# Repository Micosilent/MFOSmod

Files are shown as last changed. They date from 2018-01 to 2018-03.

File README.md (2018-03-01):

# MFOSmod

This is a collection of modules from Ray Wilson's [Music From Outer Space](http://musicfromouterspace.com/).

I will be using SMT in all the places I can, and replacing obsolete components that cant be found in the usual electronic distributors ( mouser or digikey ), with appropiate ones, following if possible Ray Wilson's advice on parts.

---

## MFOS SUPER-Modular Bundle

The idea is to end with all the modules from the supermodular bundle for starters, once we have all this modules we can look into transcripting other modules.

TODO:
- [x] 1. VCO
- [ ] 2. State Variable 12dB/Oct VCF
- [ ] 3. ADSR Envelope Generator
- [ ] 4. Mini-Controller
- [ ] 5. Dual Log/lin VCA
- [ ] 6. VC Low Frequency Oscillator
- [ ] 7. Dual AR Envelope Generator
- [ ] 8. Noise Cornucopia
- [ ] 9. Four Channel Stereo Panning Mixer
- [ ] 10. Delayed Modulation Module
- [ ] 11. Sample & Hold
- [ ] 12. Sonic Multiplier
- [ ] 13. Low Pass 24db/OCT VCF
- [ ] 14. Wave Freaker
- [ ] 15. Stereo Auto-Panner
- [ ] 16. Multi-Function Module
- [ ] 17. MFOS 8 Stage Phase Shifter
- [ ] 18. MFOS Voltage Quantizer

You dont really need all this modules to make a working synthesizer, but I am planning to make all the modules in KiCAD and start bulding them progresivly.

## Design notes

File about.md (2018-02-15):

# VCO

This is a compilation of logs and stuff that are later edited an posted on hackaday and blog.

## Log 1: Initial considerations

### Hardware
This synthesizer will be based on an eurorack form factor, as such the size for the front panel must comply with the "standard".

A typical synth enclosure is 6 HP units high, acomodating two rows of modules, each 3 high, and 84 HP units wide, so if we want a rack enclosure with 4 VCOs they should be 10 units wide, so they only take up half of the top row.

Following this guidelines, the aluminium front panel is 128.5mm high by 50.50mm width and the PCB in order to fit in normal fabhouse board size limits will be 100x50mm with a few mm of margin if we need the space.

The mounting of the pcb to the front pannel will be accomplished with the audio jacks and potentiometers, so no standoffs or mounting holes are needed.

The eurorack power connector, is a 8x2 with +-12V, +5V , GND and some control voltages, we could add a switch and do a small modification of the board, in order to accomodate for the control of the VCO with internal CV.

The frontpanel design will be transfered toner from a SVG design, and then coated with a few layers of lacquer.

The original design comes with a temperature compensator, wich after some research turns out to be synth lingo for a thermistor, a PTC thermistor to be more exact. The one used in the original design is a 2k with a very low tolerance. These have been proven difficult to find in the usual distributors, so two 1k .5% PTC thermistors in a 1206 and very close proximity to the matched transistor package will be used.

### Design

I am going to try to do a cool frontpanel design with inkscape, to help me with this I found a  bunch of plugin that im going to try. They can be downloaded 

1. Doepfer units: [here](http://syinsi.com/eurorack-panel-designer-for-inkscape/).

2. Knob scales: [here](https://github.com/leechwort/knob_scale_generator)

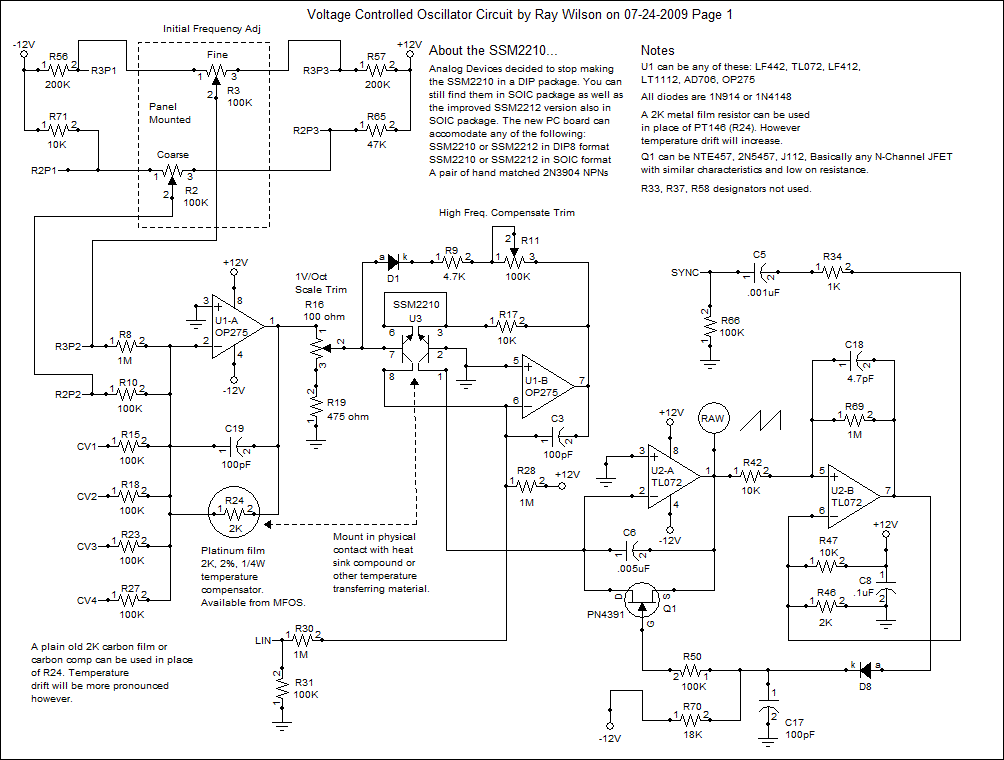
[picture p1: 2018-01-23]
VCO/media/vco20120615wsoic_page_1.gif

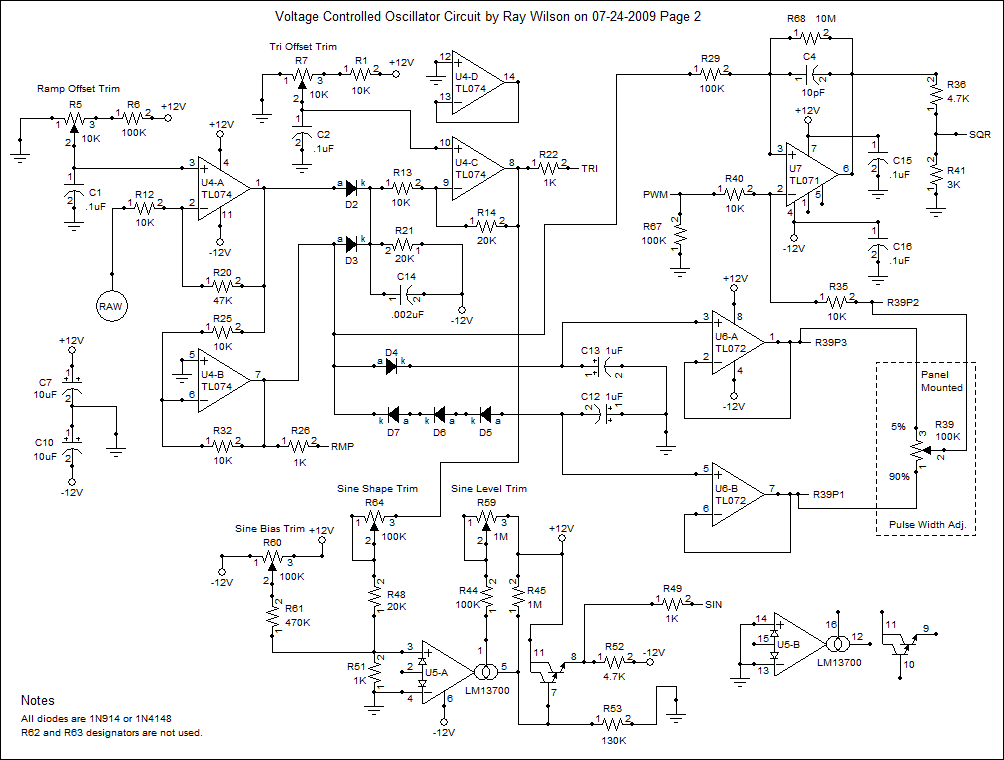
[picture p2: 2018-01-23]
VCO/media/vco20120615wsoic_page_2.gif

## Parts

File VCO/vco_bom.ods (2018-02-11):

Reference | Quantity | Value | Footprint | Digikey Part # | Comments
C1 C7 C8 | 3 | 100pF | 0603 | 399-1061-2-ND | REEL
C10 | 1 | .002uF | 0805 | 1276-2471-2-ND | REEL
C11 | 1 | 10pF | 0805 | 1276-2533-2-ND | REEL
C14 C15 | 2 | 1uF | 0805 | 1276-2448-2-ND | REEL
C2 | 1 | .005uF | 0805 | 478-10560-1-ND | REEL
C3 | 1 | .001uF | 0603 | 399-1082-2-ND | REEL
C5 | 1 | 4.7pF | 0805 | CL21C4R7BBANNNC | REEL
C12 C13 C4 C6 C9 | 5 | .1uF | 0805 | CL21B104KOANNNC | REEL
D1 D2 D3 D4 D5 D6 D7 D8 | 8 | D | miniMELF | LS4148L1GTR-ND
J1 J10 J2 J3 J4 J5 J6 J7 J8 J9 | 10 | Audio-Jack-2 |  | 486-3418-ND
J11 | 1 | Conn_02x08_Top_Bottom |  | ED10523-ND
Q1 | 1 | Q_NJFET_DSG
R47 RV4 RV8 | 3 | 10K |  | 3214W-103ECT-ND
R1 R15 R16 R19 R26 R29 R30 R35 R36 | 9 | 10K | 0805 | RMCF0805JG10K0TR-ND
R14 R42 R48 | 3 | 4.7K | 0805
R17 R31 R33 R40 R41 | 5 | 1K | 0805
R10 R2 | 2 | 200K | 0805
R20 | 1 | 2K | 0805
R25 | 1 | 18K | 0805
R27 R11 | 2 | 470K | 0805
RV9 | 1 | 1M |  | 3214W-1-105ETR-ND
R13 R21 R23 R3 R37 | 5 | 1M | 0805
R32 | 1 | 20k | 0805
R38 R39 | 2 | 20K | 0805
R43 | 1 | 130K | 0805
R46 | 1 | 10M | 0805 | RMCF0805JT10M0TR-ND
R49 | 1 | 3K | 0805
R28 R9 | 2 | 47K | 0805
RV5 RV6 RV7 |  | 100K |  | 3214W-104ECT-ND
RV1 RV2 RV10 | 3 | 100K |  | 987-1709-ND | Panel Mounted
R12 R18 R22 R24 R34 R4 R44 R45 R5 R6 R7 R8 | 15 | 100K | 0805
RV3 | 1 | 100 |  | 3214W-1-101E
TH1 TH2 | 2 | 1K PTC |  | 541-1709-1-ND
U1 | 1 | LM13700 | 16SOIC | LM13700MX-NOPBCT-ND
U2 U6 | 2 | TL072 | 8SOIC | 497-2200-1-ND
U3 | 1 | OP275 | 8SOIC | OP275GSZ-REEL7CT-ND
U4 | 1 | TL074 | 14SOIC | TL074CDT
U5 | 1 | SSM2210 | 8SOIC | SSM2212RZ-R7CT-ND | OBSOLETE, replaced by 2212
U7 | 1 | TL071 | 8SOIC | 497-4055-1-ND

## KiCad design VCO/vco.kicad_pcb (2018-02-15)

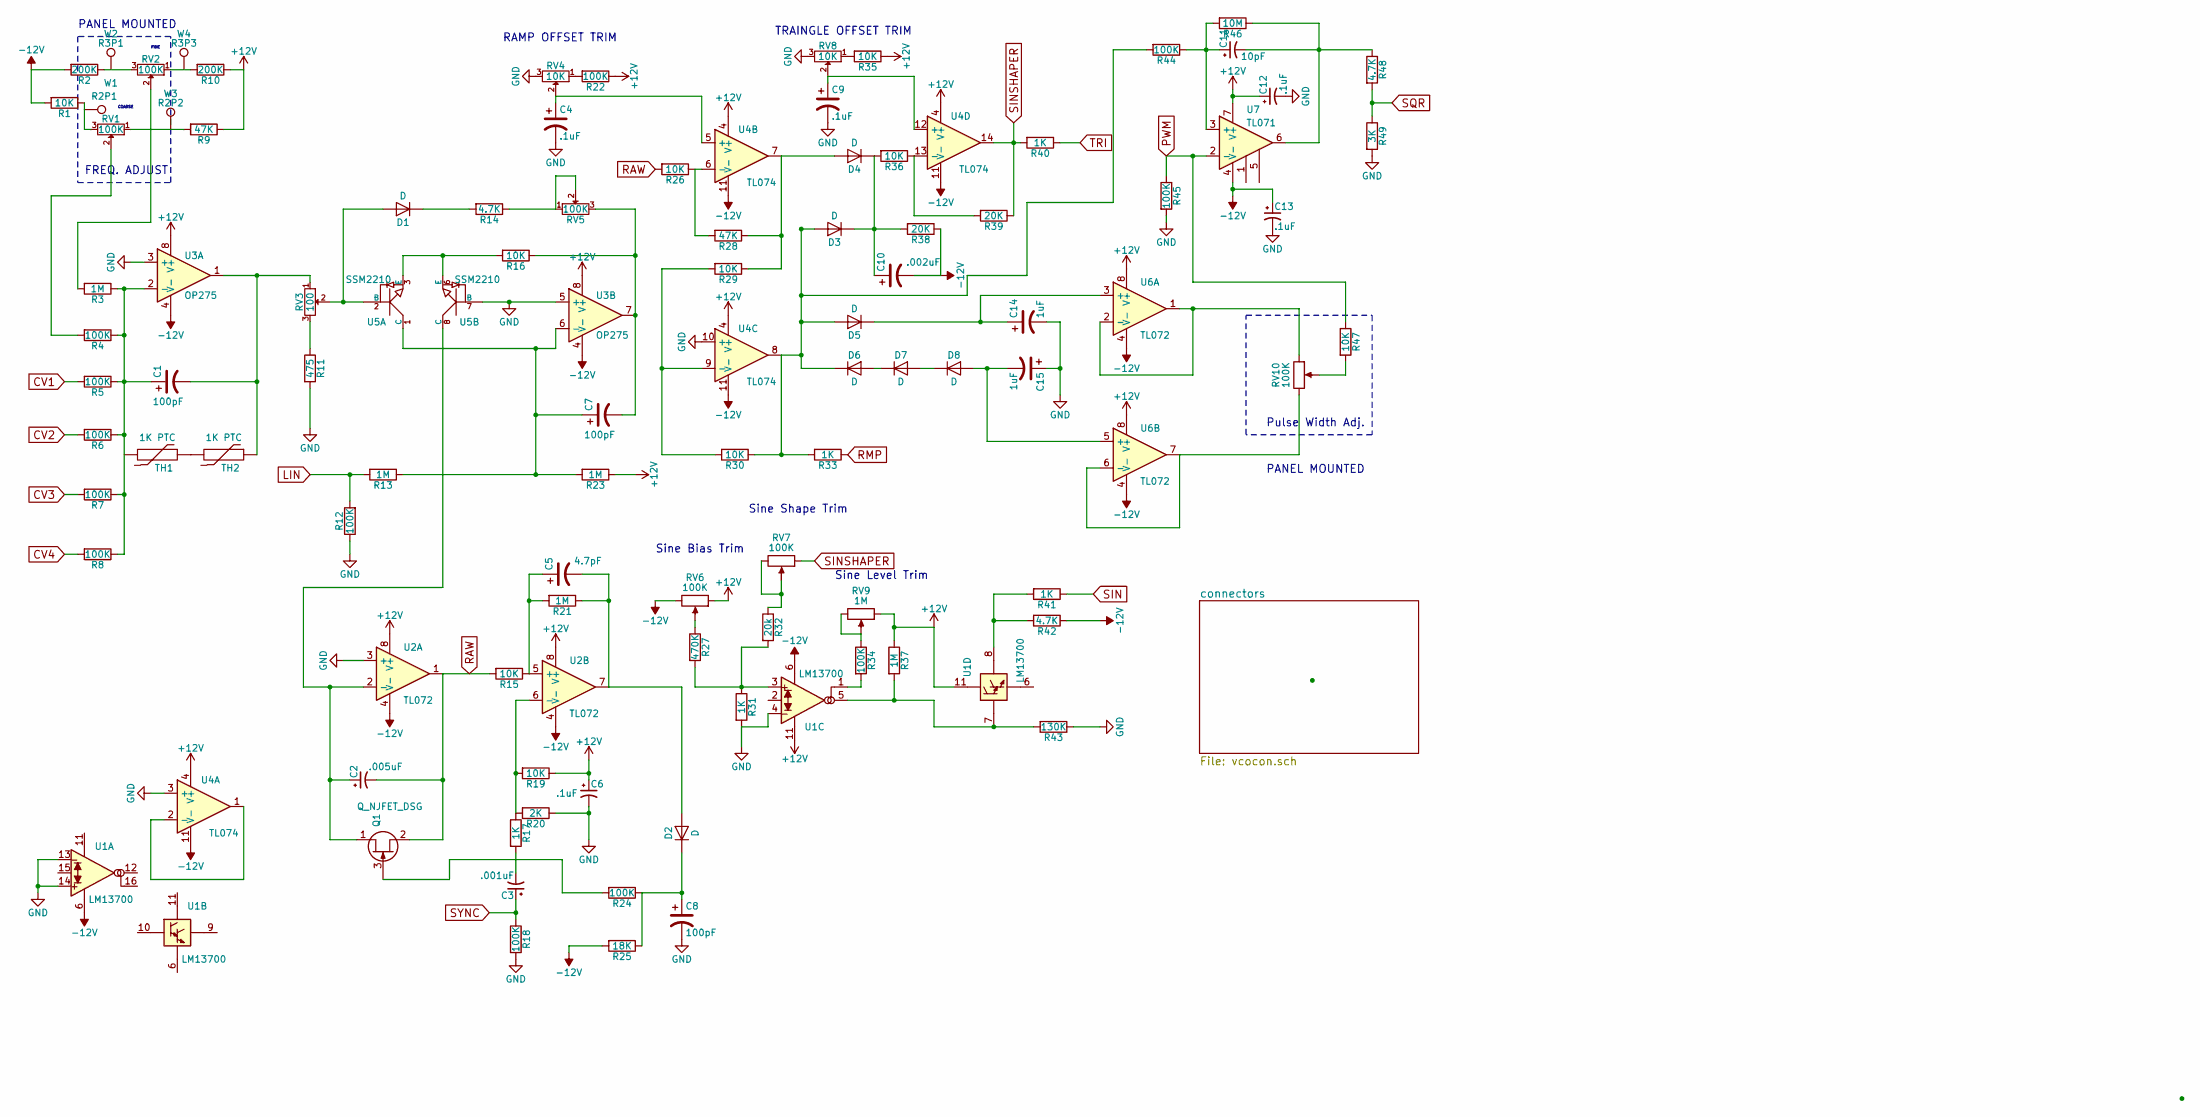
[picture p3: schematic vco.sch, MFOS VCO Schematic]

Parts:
C1, C7, C8: 100pF; C_0603
C2: .005uF; C_0805
C3: .001uF; C_0603
C4, C6, C9, C12, C13: .1uF; C_0805
C5: 4.7pF; C_0805
C10: .002uF; C_0805
C11: 10pF; C_0805
C14, C15: 1uF; C_0805
D1, D2, D3, D4, D5, D6, D7, D8: D; D_MiniMELF
Q1: Q_NJFET_DSG; SOT-23
R1, R15, R16, R19, R26, R29, R30, R35, R36, R47: 10K; R_0805
R2, R10: 200K; R_0805
R3, R13, R21, R23, R37: 1M; R_0805
R4, R5, R6, R7, R8, R12, R18, R22, R24, R34, R44, R45: 100K; R_0805
R9, R28: 47K; R_0805
R11: 475; R_0805
R14, R42, R48: 4.7K; R_0805
R17, R31, R33, R40, R41: 1K; R_0805
R20: 2K; R_0805
R25: 18K; R_0805
R27: 470K; R_0805
R32: 20k; R_0805
R38, R39: 20K; R_0805
R43: 130K; R_0805
R46: 10M; R_0805
R49: 3K; R_0805_HandSoldering
RV1, RV2, RV10: 100K; Potentiometer_Alps_RK09K_Horizontal
RV3: 100; Potentiometer_Trimmer_Bourns_3214W
RV4: 10K; Potentiometer_Trimmer_Bourns_3214W
RV5, RV6, RV7: 100K; Potentiometer_Trimmer_Bourns_3214W
RV8: 10K; Potentiometer_Trimmer_Bourns_3214X
RV9: 1M; Potentiometer_Trimmer_Bourns_3214W
TH1, TH2: 1K PTC; R_1206
U1: LM13700; SOIC-16_3.9x9.9mm_Pitch1.27mm
U2, U6: TL072; SOIC-8_3.9x4.9mm_Pitch1.27mm
U3: OP275; SOIC-8_3.9x4.9mm_Pitch1.27mm
U4: TL074; SOIC-14_3.9x8.7mm_Pitch1.27mm
U5: SSM2210; SOIC-8_3.9x4.9mm_Pitch1.27mm
U7: TL071; SOIC-8_3.9x4.9mm_Pitch1.27mm
W1: R2P1; SolderWirePad_single_2mmDrill
W2: R3P1; SolderWirePad_single_2mmDrill
W3: R2P2; SolderWirePad_single_2mmDrill
W4: R3P3; SolderWirePad_single_2mmDrill

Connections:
+12V: C6.1, C12.1, R9.1, R10.1, R19.1, R22.1, R23.1, R35.1, R37.1, RV6.1, RV9.1, U1.11 (V+), U2.8 (V+), U3.8 (V+), U4.4 (V+), U6.8 (V+), U7.7 (V+); also elsewhere on the board
-12V: C10.2, C13.1, R1.2, R2.2, R25.2, R38.1, R42.1, RV6.3, U1.6 (V-), U2.4 (V-), U3.4 (V-), U4.11 (V-), U6.4 (V-), U7.4 (V-); also elsewhere on the board
CV1: R5.2; also elsewhere on the board
CV2: R6.2; also elsewhere on the board
CV3: R7.2; also elsewhere on the board
GND: C4.2, C6.2, C8.2, C9.2, C12.2, C13.2, C14.2, C15.1, R11.2, R12.1, R18.2, R20.1, R31.2, R43.1, R45.2, R49.2, RV4.3, RV8.3, U1.4 (INPUT(-)), U1.13 (INPUT(-)), U1.14 (INPUT(+)), U2.3 (+), U3.3 (+), U3.5 (+), U4.3 (+), U4.10 (+), U5.7 (B); also elsewhere on the board
LIN: R12.2, R13.2; also elsewhere on the board
unnamed: C1.1, R3.1, R4.1, R5.1, R6.1, R7.1, R8.1, U3.2 (-)
unnamed: C1.2, RV3.1, TH2.1, U3.1
unnamed: C2.1, Q1.1 (D), U2.2 (-), U5.8 (C)
unnamed: C3.2, R17.2
unnamed: C4.1, RV4.2, U4.5 (+)
unnamed: C5.1, R15.1, R21.2, U2.5 (+)
unnamed: C5.2, D2.2 (A), R21.1, U2.7
unnamed: C7.1, R13.1, R23.2, U3.6 (-), U5.1 (C)
unnamed: C7.2, R16.1, RV5.3, U3.7
unnamed: C8.1, D2.1 (K), R24.1, R25.1
unnamed: C9.1, RV8.2, U4.12 (+)
unnamed: C10.1, D3.1 (K), D4.1 (K), R36.2, R38.2
unnamed: C11.1, R44.1, R46.2, U7.3 (+)
unnamed: C11.2, R46.1, R48.1, U7.6
unnamed: C14.1, D5.1 (K), U6.3 (+)
unnamed: C15.2, D8.2 (A), U6.5 (+)
unnamed: D1.1 (K), R14.2
unnamed: D1.2 (A), RV3.2, U5.2 (B)
unnamed: D3.2 (A), D5.2 (A), D6.1 (K), R30.1, R33.2, R44.2, U4.8
unnamed: D4.2 (A), R28.1, R29.1, U4.7
unnamed: D6.2 (A), D7.1 (K)
unnamed: D7.2 (A), D8.1 (K)
unnamed: Q1.3 (G), R24.2
unnamed: R1.1, RV1.3
unnamed: R2.1, RV2.3
unnamed: R3.2, RV2.2
unnamed: R4.2, RV1.2
unnamed: R9.2, RV1.1
unnamed: R10.2, RV2.1
unnamed: R11.1, RV3.3
unnamed: R14.1, RV5.1, RV5.2
unnamed: R16.2, U5.3 (E), U5.6 (E)
unnamed: R17.1, R19.2, R20.2, U2.6 (-)
unnamed: R22.2, RV4.1
unnamed: R26.1, R28.2, U4.6 (-)
unnamed: R27.1, RV6.2
unnamed: R27.2, R31.1, R32.2, U1.3 (INPUT(+))
unnamed: R29.2, R30.2, U4.9 (-)
unnamed: R32.1, RV7.2, RV7.3
unnamed: R34.1, RV9.2, RV9.3
unnamed: R34.2, U1.1 (AMP_BIAS_INPUT)
unnamed: R35.2, RV8.1
unnamed: R36.1, R39.2, U4.13 (-)
unnamed: R37.2, R43.2, U1.5 (OUTPUT), U1.7 (BUFFER_INPUT)
unnamed: R41.2, R42.2, U1.8 (BUFFER_OUTPUT)
unnamed: R47.2, RV10.2
unnamed: RV10.1, U6.1, U6.2 (-)
unnamed: RV10.3, U6.6 (-), U6.7
unnamed: TH1.1, TH2.2
unnamed: U4.1, U4.2 (-)
PWM: R45.1, R47.1, U7.2 (-); also elsewhere on the board
RAW: C2.2, Q1.2 (S), R15.2, R26.2, U2.1
RMP: R33.1; also elsewhere on the board
SIN: R41.1; also elsewhere on the board
SINSHAPER: R39.1, R40.2, RV7.1, U4.14
SQR: R48.2, R49.1; also elsewhere on the board
SYNC: C3.1, R18.1; also elsewhere on the board
TRI: R40.1; also elsewhere on the board

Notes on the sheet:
FREQ. ADJUST
COARSE
FINE
RAMP OFFSET TRIM
TRAINGLE OFFSET TRIM
Sine Bias Trim
Sine Shape Trim
Sine Level Trim
Pulse Width Adj.
PANEL MOUNTED

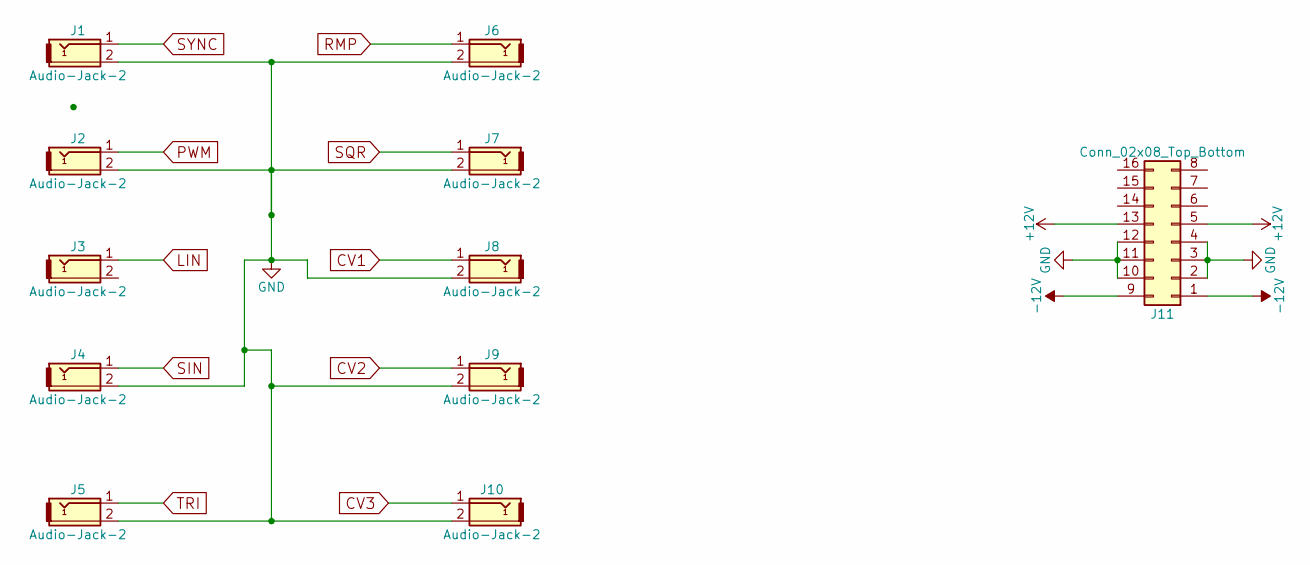
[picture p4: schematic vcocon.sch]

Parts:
J1, J2, J3, J4, J5, J6, J7, J8, J9, J10: Audio-Jack-2; audio_jack_3.5mm_schurter
J11: Conn_02x08_Top_Bottom; Molex_NanoFit_2x08x2.50mm_Straight

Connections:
+12V: J11.5, J11.13; also elsewhere on the board
-12V: J11.1, J11.9; also elsewhere on the board
CV1: J8.1; also elsewhere on the board
CV2: J9.1; also elsewhere on the board
CV3: J10.1; also elsewhere on the board
GND: J1.2, J2.2, J4.2, J5.2, J6.2, J7.2, J8.2, J9.2, J10.2, J11.2, J11.3, J11.4, J11.10, J11.11, J11.12; also elsewhere on the board
LIN: J3.1; also elsewhere on the board
PWM: J2.1; also elsewhere on the board
RMP: J6.1; also elsewhere on the board
SIN: J4.1; also elsewhere on the board
SQR: J7.1; also elsewhere on the board
SYNC: J1.1; also elsewhere on the board
TRI: J5.1; also elsewhere on the board

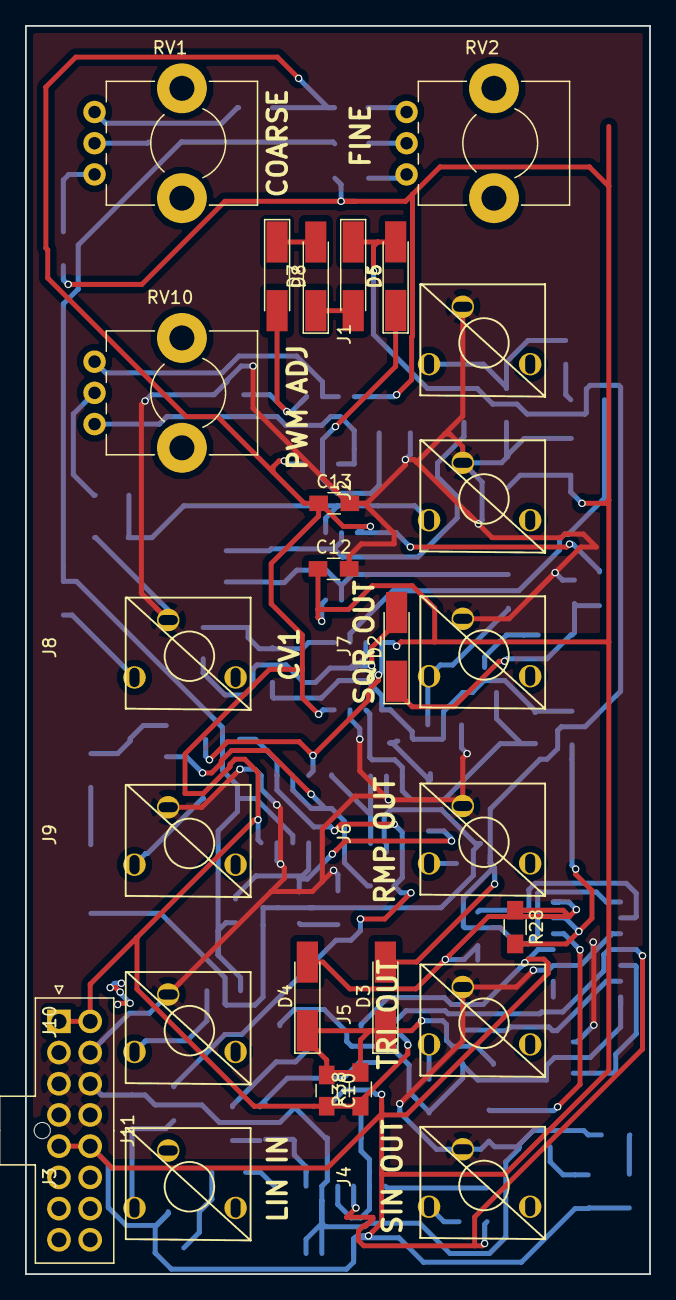
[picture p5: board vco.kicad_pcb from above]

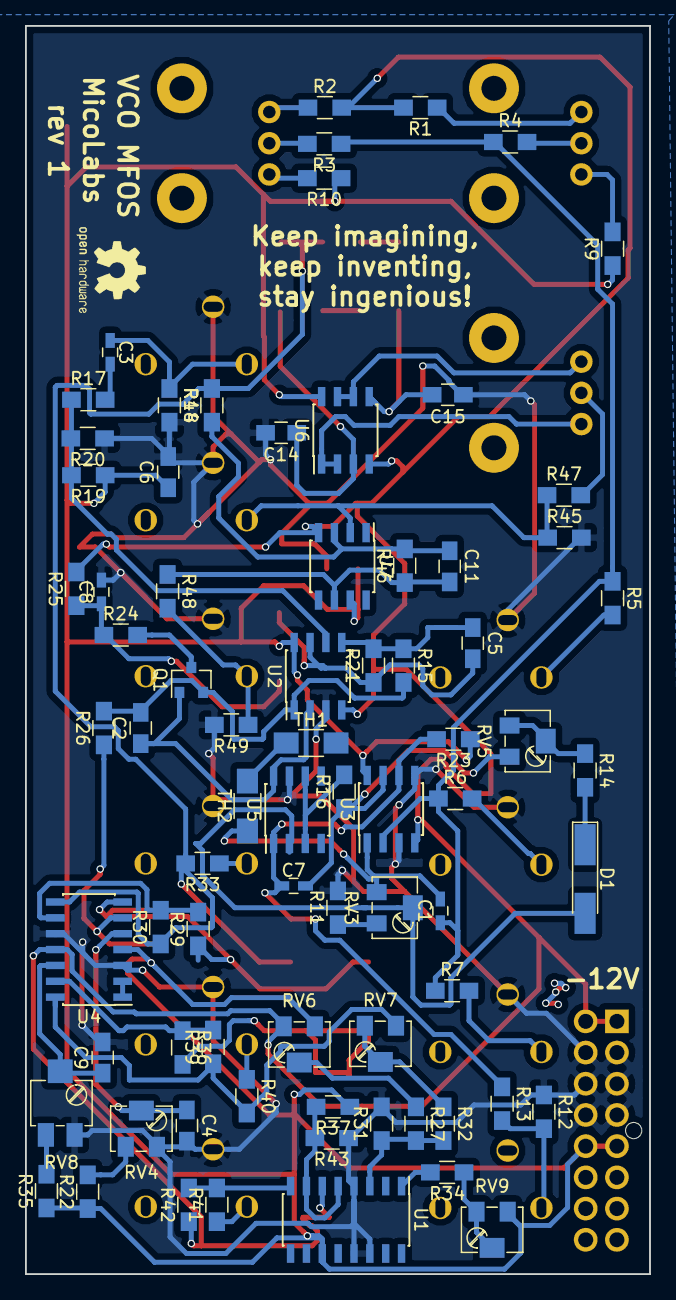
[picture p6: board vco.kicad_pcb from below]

Board: 2 copper layers, 50.0 x 100.0 mm, 102 parts (76 on the bottom side), 65 nets.

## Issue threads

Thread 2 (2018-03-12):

Fix Libraries

Micosilent, 2018-03-12:
All modules created with KiCAD4 need no be rechecked to update their libraries to the KiCAD5rc library system.

This currently affects the following:

* VCO
*  ADSREnv

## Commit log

2018-01-23 VCO core schematic
    Starting up with the essential module, the VCO. The waveshaping part of the schematic is still missing, along with the PCB files
    [vco.kicad_pcb, vco.sch]
2018-02-11 VCO update
    vco pcb, gerbers and bom updated
    [vco.kicad_pcb, vco.sch, vco_bom.ods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]
2018-02-11 Drill File
    Forgot to add the drill file to the gerbres
    [vco.drl]
2018-02-15 Missing SilkScreen
    Added missing files for fabrication
    [vco.kicad_pcb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]
2018-03-12 test 1 VCF
    [vcf.kicad_pcb, vcf.sch]
